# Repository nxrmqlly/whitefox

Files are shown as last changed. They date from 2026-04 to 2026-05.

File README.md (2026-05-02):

# whitefox :: an RP2350B devboard
> 💥 very chonky!

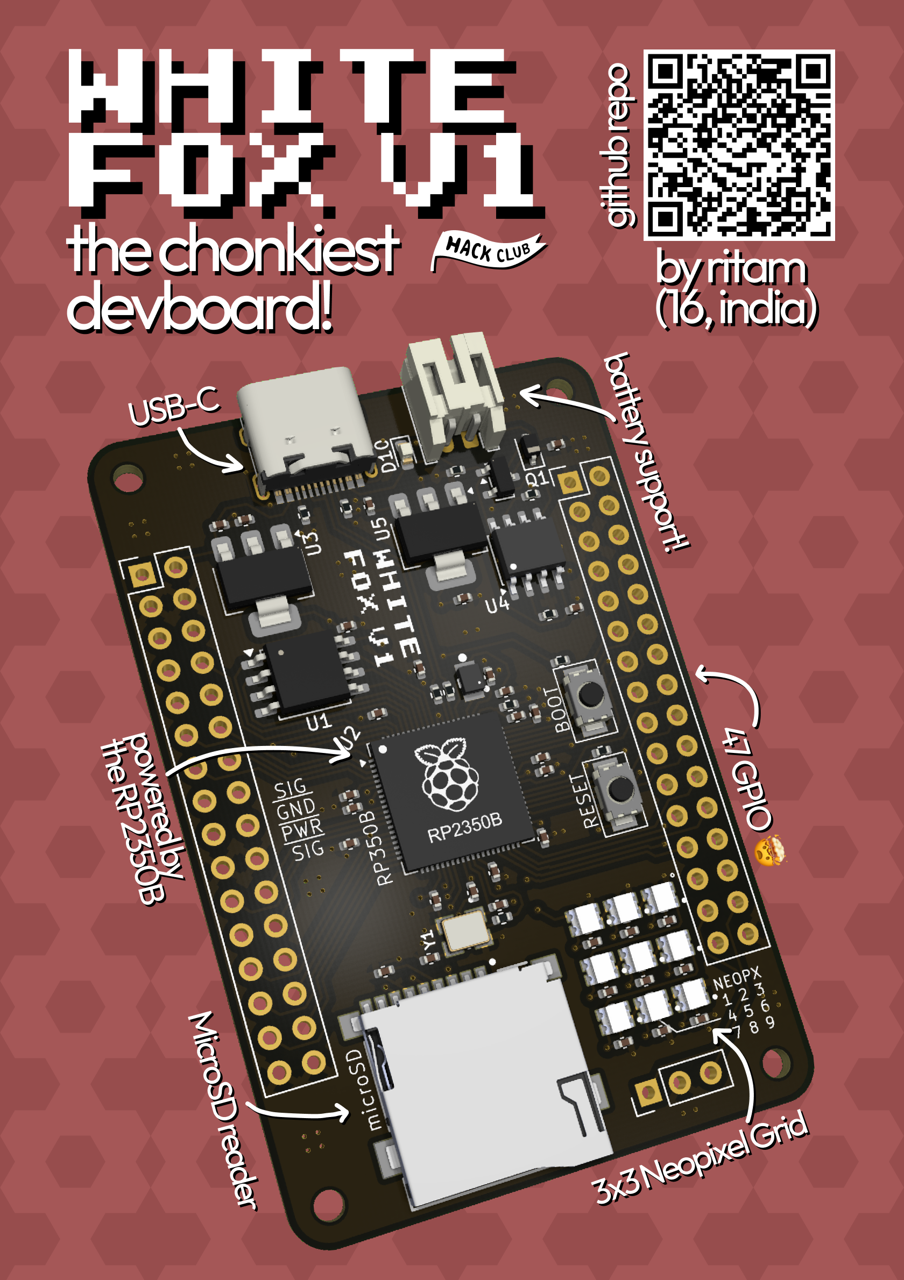
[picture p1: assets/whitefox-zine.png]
whitefox v1 magazine page


## What's this? ooh shiny.

whitefox is a Raspberry Pi RP2350B based **devboard** with *47 exposed GPIO, a 3x3 neopixel grid, a charging circuit and a MicroSD card reader* onboard!
Some may even say that it is *batteries included* but sorry we don't include batteries :(

## Why?

I wanted to have a go at making a devboard so I initially thought of using the RP2040 Chip but that thing is old now and very overused so here
we are with the RP2040's successor, the RP2350! Most RP2350 boards (like the Raspberry Pi Pico *2*) use the QFN-60 layout on the RP2350A chip 
and I haven't really seen devboards use the RP2350B, which is a QFN-80 chip, meaning it exposes the full power of the RP2350 in a bigger die.

## The PCB

The Schematic is a combination of very many different projects and the official and amazing
[Hardware design with RP2350](https://pip-assets.raspberrypi.com/categories/1214-rp2350/documents/RP-008280-DS-1-hardware-design-with-rp2350.pdf)
The PCB is configured in a 4 layer stackup as follows (from the top): `SIG / GND / PWR / SIG` and includes copper pours on all layers except
the PWR layer (duh.)
Most components are SMD on top of the board, only the JST connector is through hole.

The PCB exposes two 2x16 standard 2.54 mm pitch header holes on both sides and an additional 1x3 2.54mm pitch connector as a debug header.

| What | Image |
|---|---|
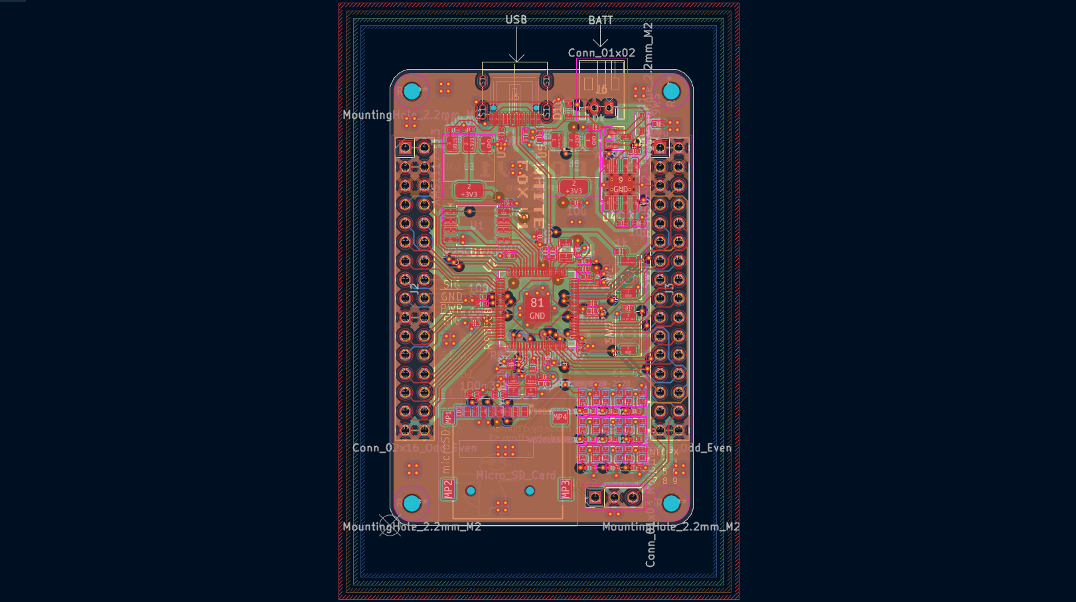
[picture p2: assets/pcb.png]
pcb
| [PCB](./Docs/whitefox-pcb.pdf) |  |
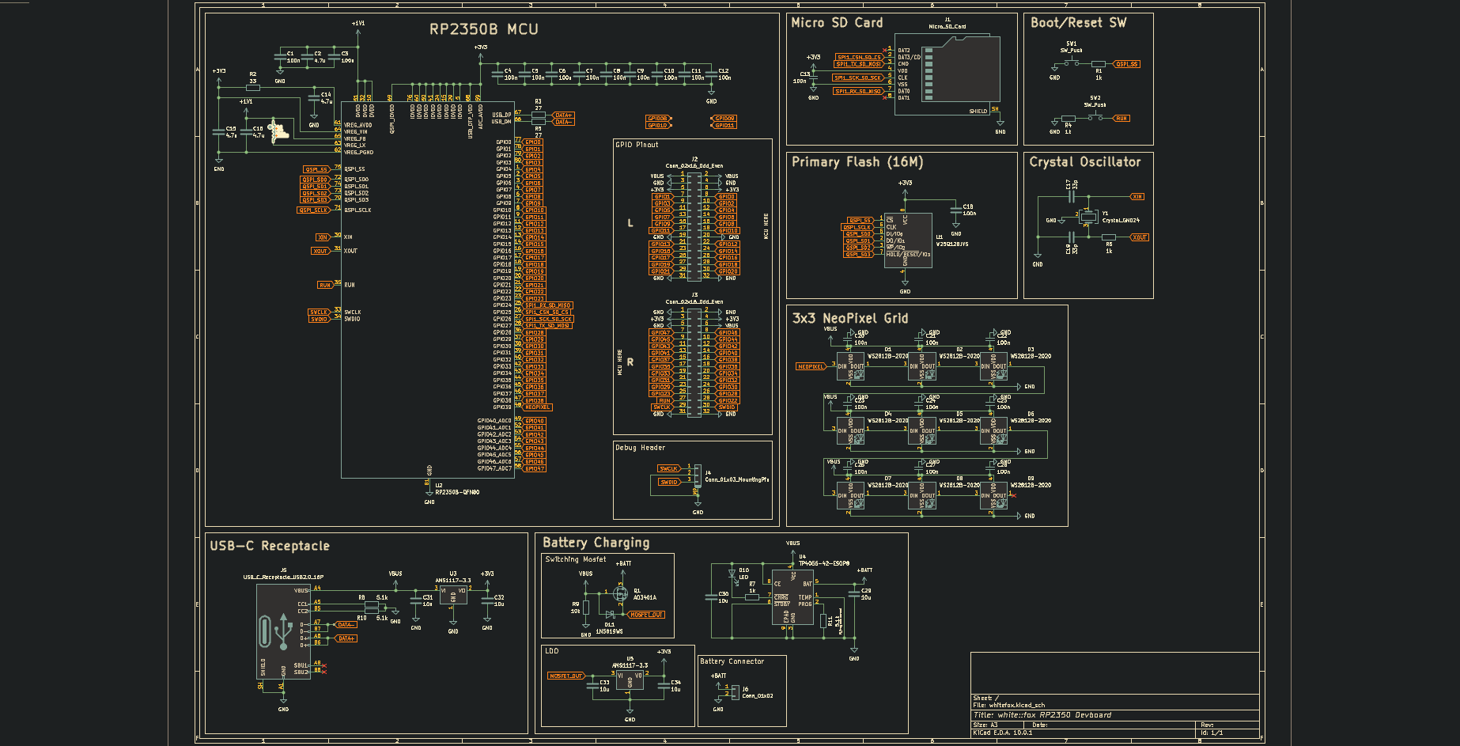
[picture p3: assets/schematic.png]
schematic
| [Schematic](./Docs/whitefox-schematic.pdf) |  |

The PCB and Schematic are available in a high quality PDFs in [Docs/](Docs/)

## 3D stuff
| <center>Front</center> | <center>Back</center> |
|---|---|
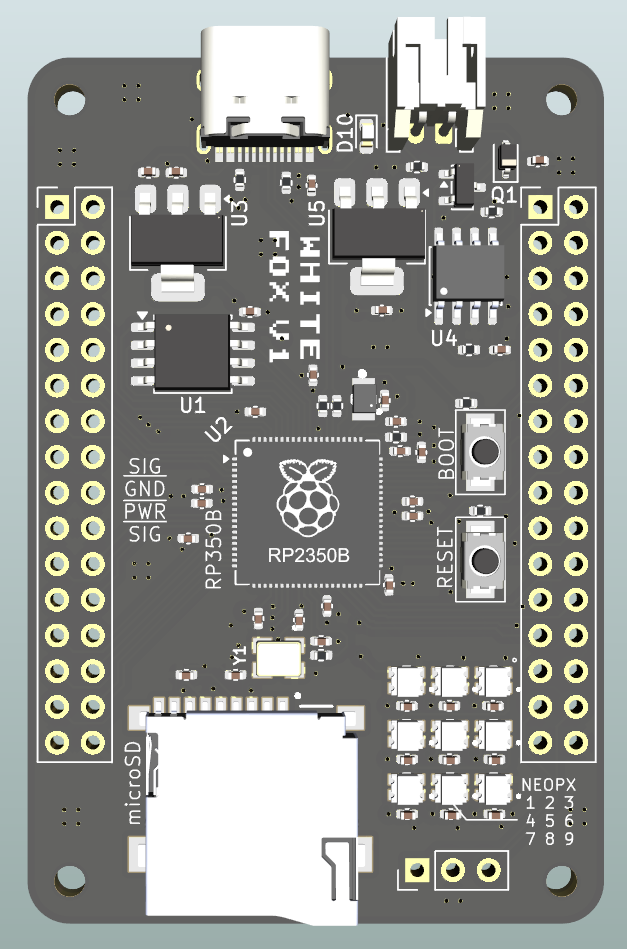
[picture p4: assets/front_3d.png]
3d front
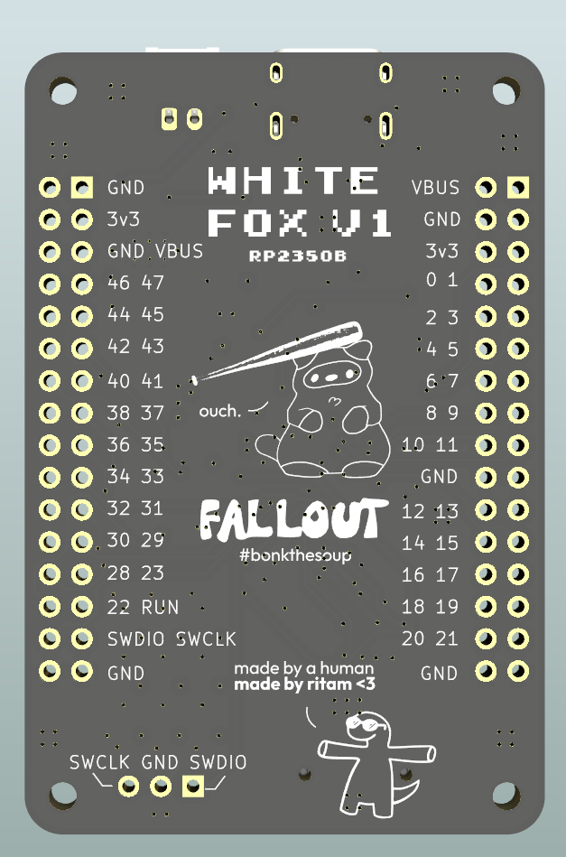
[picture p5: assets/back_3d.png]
3d back
|  |  |

## The BOM

Lazy to type it here so...

The full BOM can be found at [BOM/bom.csv](./BOM/BOM.csv)!

## Why the name?

> There are 2 hard problems in computer science: cache invalidation, **naming things**, and off-by-1 errors.
>
> *-- Leon Bambrick*

yeah that should be enough for an explanation.

## How to build / use it IRL

1. Spend some \$\$\$ get parts from the [BOM](./BOM/BOM.csv)
2. Use the gerbers from [production/gerbers.zip](production/gerbers.zip) to fabricate a PCB.
3. With some elbow grease and reference from the schematic, get to soldering the tiny SMD components
4. You're done! Go crazy

Alternatively, you can preserve your sanity and [get a PCBA service instead.](https://jlcpcb.com)
1. Gerbers are at [production/gerbers.zip](production/gerbers.zip)
2. JLCPCB BOM (not project bom!!) is at [production/jlc_bom.csv](production/jlc_bom.csv)
3. Pick and Place (CPL) file is at [production/positions.csv](production/positions.csv)

## Credits where credits are due.

Grateful for:
- [euvalennn's RPBoard^2](https://github.com/euvalennn/rpboard-squared) for a lot of design inspiration and schematic help.
- [Fallout by hackclub](https://fallout.hackclub.com/) for giving me the oppourtunity and public brand assets!
- hackclub slack for the coolest people that helped out!

## License

The hardware (PCB) is licensed under `CERN Open Hardware Licence Version 2 - Strongly Reciprocal` which means, you're all-right to copy my work and use it in yours but you must disclose your source code and project files to opensource repositories if you include part of my work in yours. See [LICENSE](LICENSE).

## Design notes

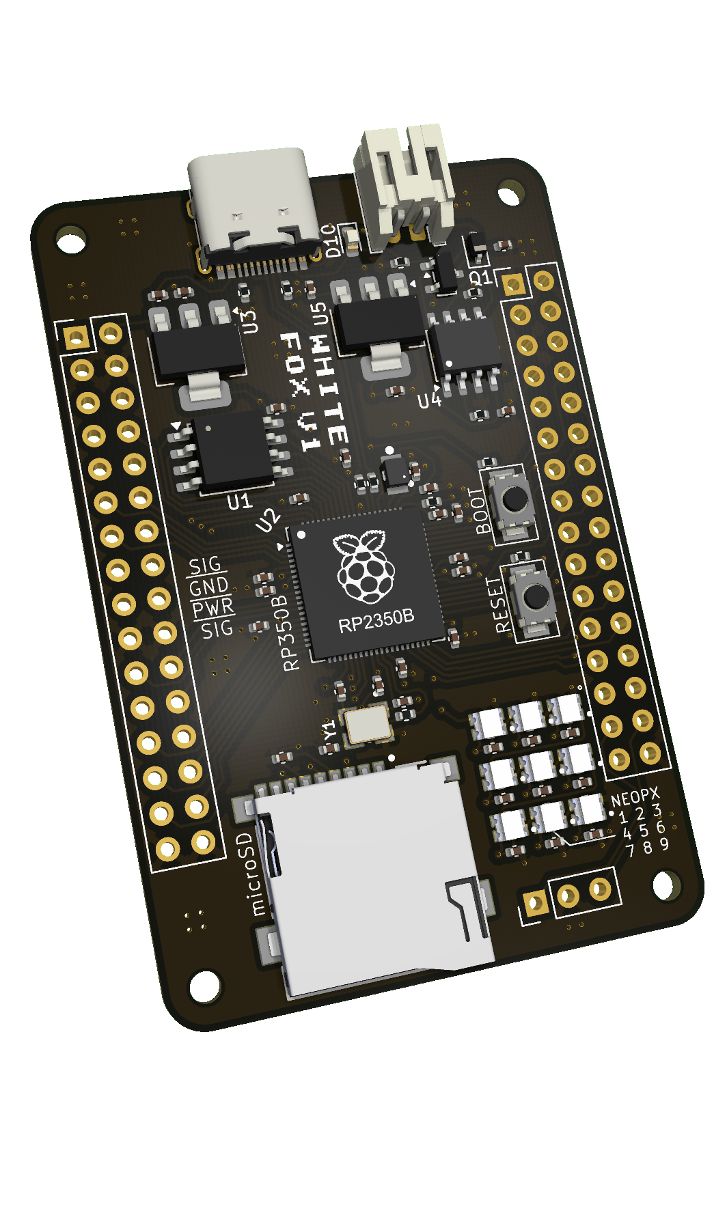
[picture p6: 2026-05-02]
assets/angled_3d_raytrace.png

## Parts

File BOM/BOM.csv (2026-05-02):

Name | Description | Quantity | JLCPCB Part # | Cost (USD) | Link | Notes
RP2350B | QFN-80-EP Microcontrollers (MCU/MPU/SOC) ROHS | 1 | C42415655 | 1.26 | https://jlcpcb.com/partdetail/RaspberryPi-RP2350B/C42415655 | Microcontroller
W25Q128JVSIQ | 128Mbit 133MHz SPI SOIC-8-208mil NOR FLASH ROHS | 1 | C97521 | 1.89 | https://jlcpcb.com/partdetail/WinbondElec-W25Q128JVSIQ/C97521 | 16M Flash QSPI
AMS1117-3.3 | 15V 1A 3.3V 5mA 72dB@(120Hz) Fixed Positive SOT-223 Voltage Regulators - Linear, Low Drop Out (LDO) Regulators ROHS | 2 | C6186 | 0.42 | https://jlcpcb.com/partdetail/Advanced_MonolithicSystems-AMS1117_33/C6186 | Voltage Regulator
TP4056-42-ESOP8 | Charging IC Lithium Battery Support ESOP-8 Battery Management ROHS | 1 | C16581 | 0.18 | https://jlcpcb.com/partdetail/17264-TP4056_42ESOP8/C16581 | Battery Manager
TF-01A | 1.85mm Connector and Ejector MicroSD Card (TF Card) Push-Push With Locating Pins SMD SD Card / Memory Card Connector ROHS | 1 | C91145 | 0.19 | https://jlcpcb.com/partdetail/Korean_HropartsElec-TF01A/C91145 | MicroSD Push-Push
X322512MSB4SI | -40℃~+85℃ 12MHz 20pF Crystal Oscillator ±10ppm ±20ppm SMD3225-4P Crystals ROHS | 1 | C9002 | 0.07 | https://jlcpcb.com/partdetail/YXC_CrystalOscillators-X322512MSB4SI/C9002 | Crystal
TS-1088-AR02016 | 12V 2mm 3mm 4mm 50mA Black Round Button SMD(SMT) Tactile Switches ROHS | 2 | C720477 | 0.12 | https://jlcpcb.com/partdetail/XUNPU-TS_1088AR02016/C720477 | Boot/Reset SW
WS2812C-2020-V1 | SMD, 2x2mm RGB LEDs(Built-in IC) ROHS | 9 | C2976072 | 0.87 | https://jlcpcb.com/partdetail/Worldsemi-WS2812C_2020V1/C2976072 | NeoPixel 2020
TYPE-C-31-M-12 | Right Angle Type-C SMD USB Connectors ROHS | 1 | C165948 | 0.18 | https://jlcpcb.com/partdetail/Korean_HropartsElec-TYPE_C_31_M12/C165948 | USB-C Receptacle
AO3401A | 1 P-Channel 14nC@10V 30V 47mΩ@10V、60mΩ@4.5V、85mΩ@2.5V 4A 55pF 645pF 80pF 900mV SOT-23 MOSFETs ROHS | 1 | C15127 | 0.06 | https://jlcpcb.com/partdetail/Alpha_OmegaSemicon-AO3401A/C15127 | Mosfet
AOTA-B201610S3R3-101-T | 0806 Power Inductors ROHS | 1 | C42411119 | 0.29 | https://jlcpcb.com/partdetail/AbraconLLC-AOTA_B201610S3R3_101T/C42411119 | 3.3uH
KT-0603R | 1.8V~2.4V 120° 20mA 300mcd 40mW 615nm~630nm 645nm Discrete Diode Red Water Clear 0603 LED Indication - Discrete ROHS | 1 | C2286 | 0.01 | https://jlcpcb.com/partdetail/Hubei_KENTOElec-KT0603R/C2286 | Red LED
1N5819WS | SOD-323 Schottky Diodes ROHS | 1 | C191023 | 0.01 | https://jlcpcb.com/partdetail/GuangdongHottech-1N5819WS/C191023 | Diode
CL05B104KO5NNNC | 100nF 16V X7R ±10% 0402 Multilayer Ceramic Capacitors MLCC - SMD/SMT ROHS | 22 | C1525 | 0.03 | https://jlcpcb.com/partdetail/1877-CL05B104KO5NNNC/C1525 | 100nF
CL05A475MP5NRNC | 10V 4.7uF X5R ±20% 0402 Multilayer Ceramic Capacitors MLCC - SMD/SMT ROHS | 4 | C23733 | 0.02 | https://jlcpcb.com/partdetail/24469-CL05A475MP5NRNC/C23733 | 4.7uF
0402CG330J500NT | 33pF 50V C0G ±5% 0402 Multilayer Ceramic Capacitors MLCC - SMD/SMT ROHS | 2 | C1562 | 0.01 | https://jlcpcb.com/partdetail/1914-0402CG330J500NT/C1562 | 33pF
CL05A475MP5NRNC | 10uF 6.3V X5R ±20% 0402 Multilayer Ceramic Capacitors MLCC - SMD/SMT ROHS | 6 | C15525 | 0.04 | https://jlcpcb.com/partdetail/16204-CL05A106MQ5NUNC/C15525 | 10uF
0402WGF1001TCE | 1kΩ 50V 62.5mW Thick Film Resistor ±1% ±100ppm/℃ 0402 Chip Resistor - Surface Mount ROHS | 4 | C11702 | 0.01 | https://jlcpcb.com/partdetail/12256-0402WGF1001TCE/C11702 | 1k ohm
0402WGF330JTCE | 33Ω 50V 62.5mW Thick Film Resistor ±1% ±100ppm/℃ 0402 Chip Resistor - Surface Mount ROHS | 1 | C25105 | 0.01 | https://jlcpcb.com/partdetail/25848-0402WGF330JTCE/C25105 | 33 ohm
0402WGF270JTCE | 27Ω 50V 62.5mW Thick Film Resistor ±1% ±100ppm/℃ 0402 Chip Resistor - Surface Mount ROHS | 2 | C25100 | 0.01 | https://jlcpcb.com/partdetail/25843-0402WGF270JTCE/C25100 | 27 ohm
0402WGF1002TCE | 10kΩ 50V 62.5mW Thick Film Resistor ±1% ±100ppm/℃ 0402 Chip Resistor - Surface Mount ROHS | 1 | C25744 | 0.01 | https://jlcpcb.com/partdetail/26487-0402WGF1002TCE/C25744 | 10k ohm
0402WGF5101TCE | 5.1kΩ 50V 62.5mW Thick Film Resistor ±1% ±100ppm/℃ 0402 Chip Resistor - Surface Mount ROHS | 3 | C25905 | 0.01 | https://jlcpcb.com/partdetail/26648-0402WGF5101TCE/C25905 | 5.1k ohm
S2B-PH-K-S(LF)(SN) | 2mm 4.8mm 5.9mm 7.6mm Brass K Pin PA66 PH Right Angle Tin UL94V-0 White P=2mm Wire To Board Connector ROHS | 1 | C173752 | 0.04 | https://jlcpcb.com/partdetail/JST-S2B_PH_K_S_LF_SN/C173752 | JST Connector PH
PARTS TOTAL |  |  |  | 5.74
JLCPCB PCB | 4-layer, 1.6mm, Black | 5 |  | 14.9
JLCPCB PCBA | PCB Assembly (Including Parts) | 2 |  | 86.16
Baking Cost |  |  |  | 7.29 |  | For LEDs
HARDWARE TOTAL |  |  |  | 108.35
SHIPPING |  |  |  | 9.02
DISCOUNT |  |  |  | 0 |  | To be added
GRAND TOTAL |  |  |  | 117.37

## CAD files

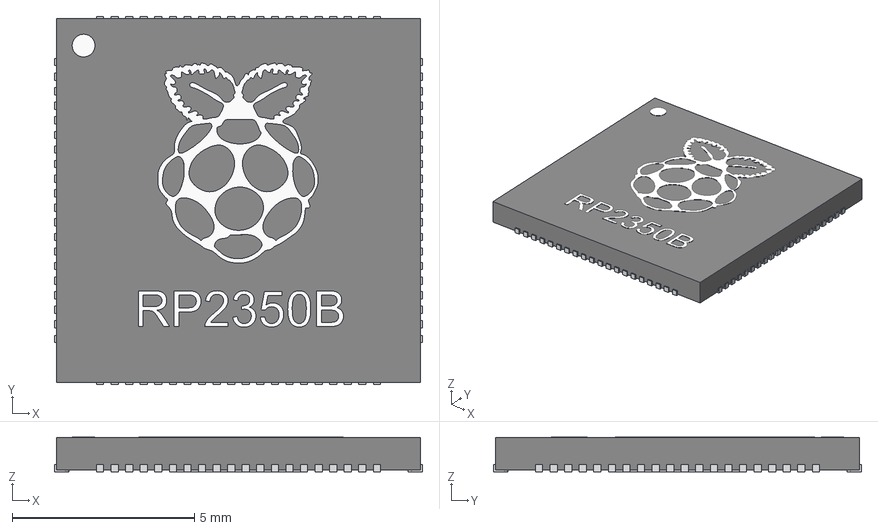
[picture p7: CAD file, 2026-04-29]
3d/RP2350/RP2350B.stp
10.1 x 10.1 x 0.96 mm

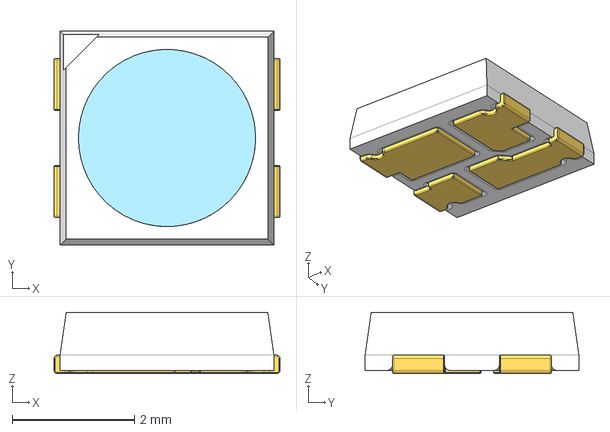
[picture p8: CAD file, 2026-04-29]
3d/SK6812-SMD3535/SK6812-SMD3535.stp
3.70 x 3.50 x 1.00 mm

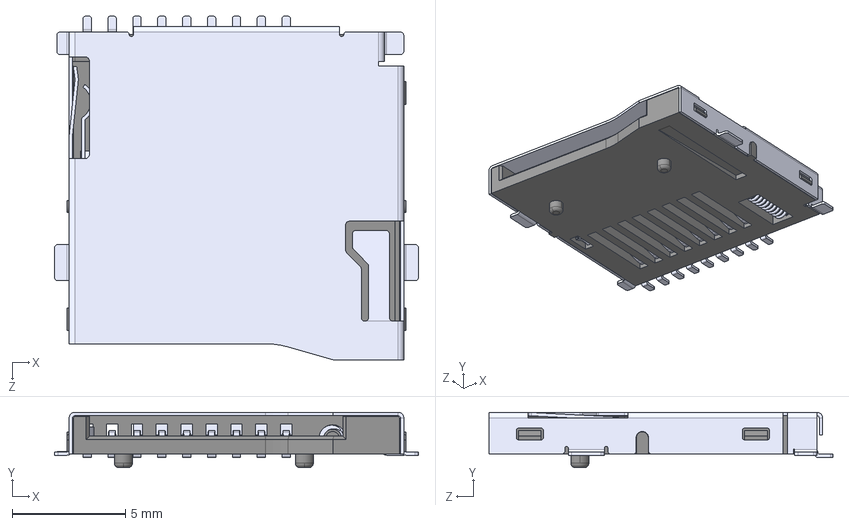
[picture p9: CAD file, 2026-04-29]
3d/TF-01A/TF-01A.STEP
16.1 x 2.45 x 15.2 mm

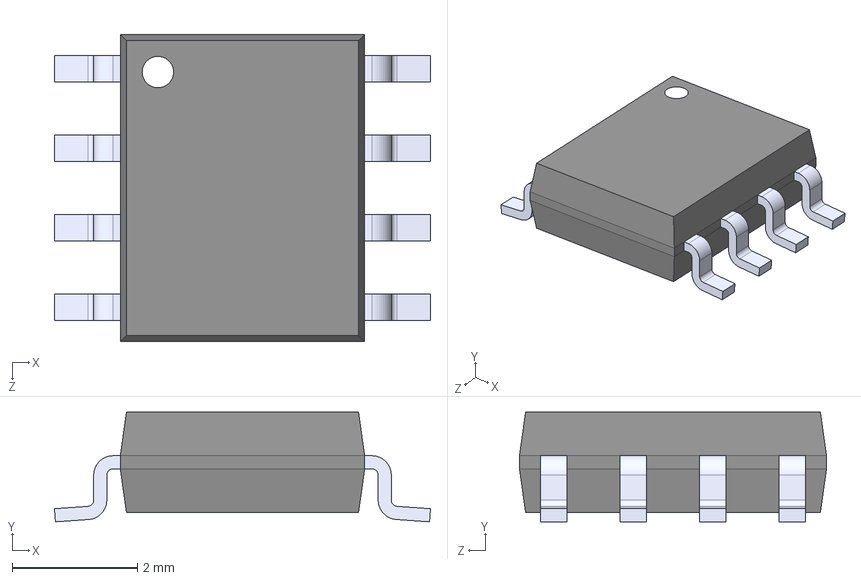
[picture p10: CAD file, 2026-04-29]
3d/TP4046-42-ESOP8/TP4056-42-ESOP8.STEP
6.00 x 1.75 x 4.90 mm

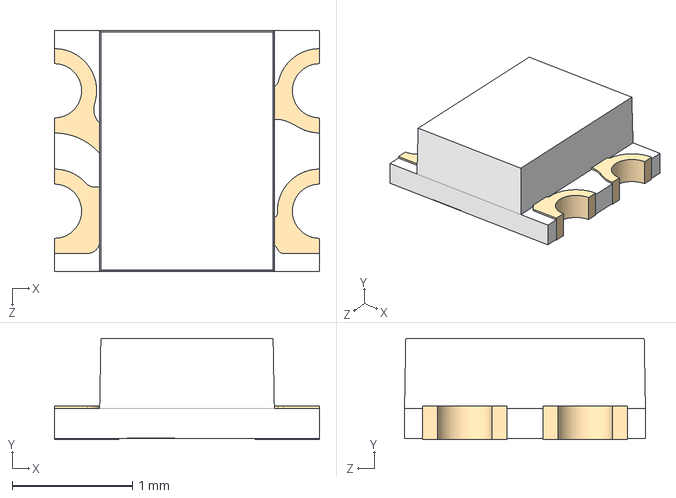
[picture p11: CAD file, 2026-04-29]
3d/WS2812B-2020/WS2812B-2020.STEP
2.20 x 0.84 x 2.00 mm

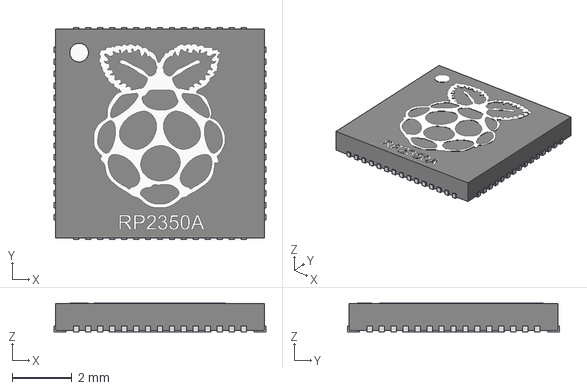
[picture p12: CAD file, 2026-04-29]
3d/RP2350/RP2350A.stp
7.10 x 7.10 x 0.96 mm

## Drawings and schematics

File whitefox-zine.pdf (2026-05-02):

## white

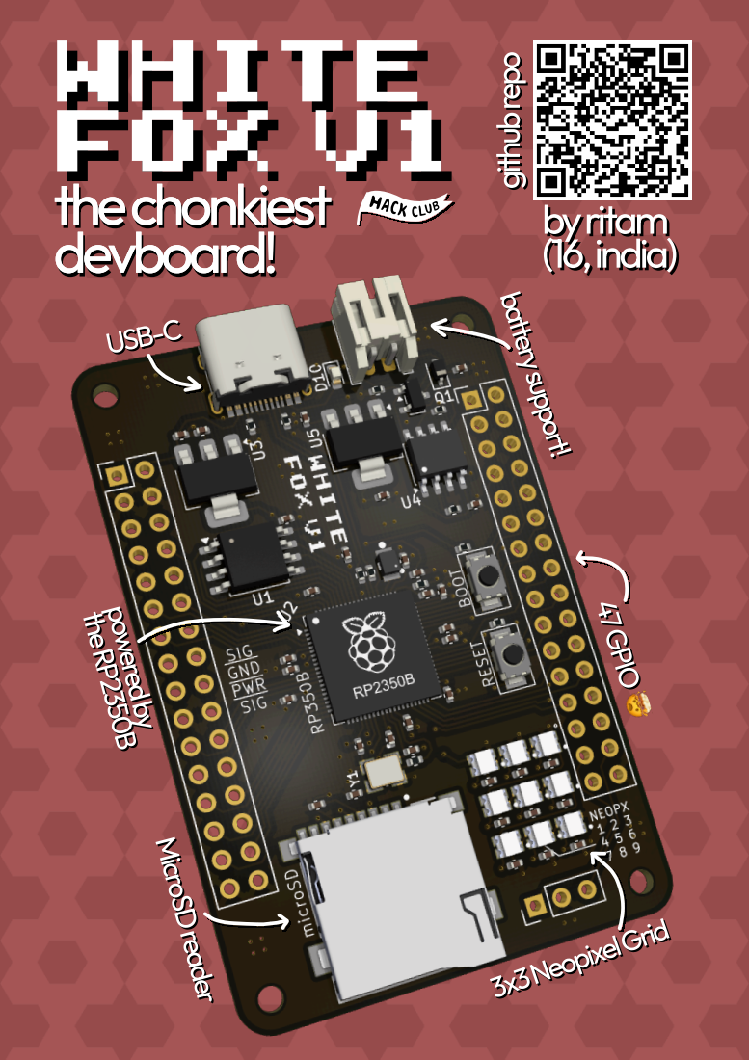
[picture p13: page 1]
fox; v1 the chonkiest; devboard!; USB-C; github repo; by ritam (16, india) battery support!; the RP2350B; powered by; MicroSD reader; 3x3 Neopixel Grid; 47 GPIO

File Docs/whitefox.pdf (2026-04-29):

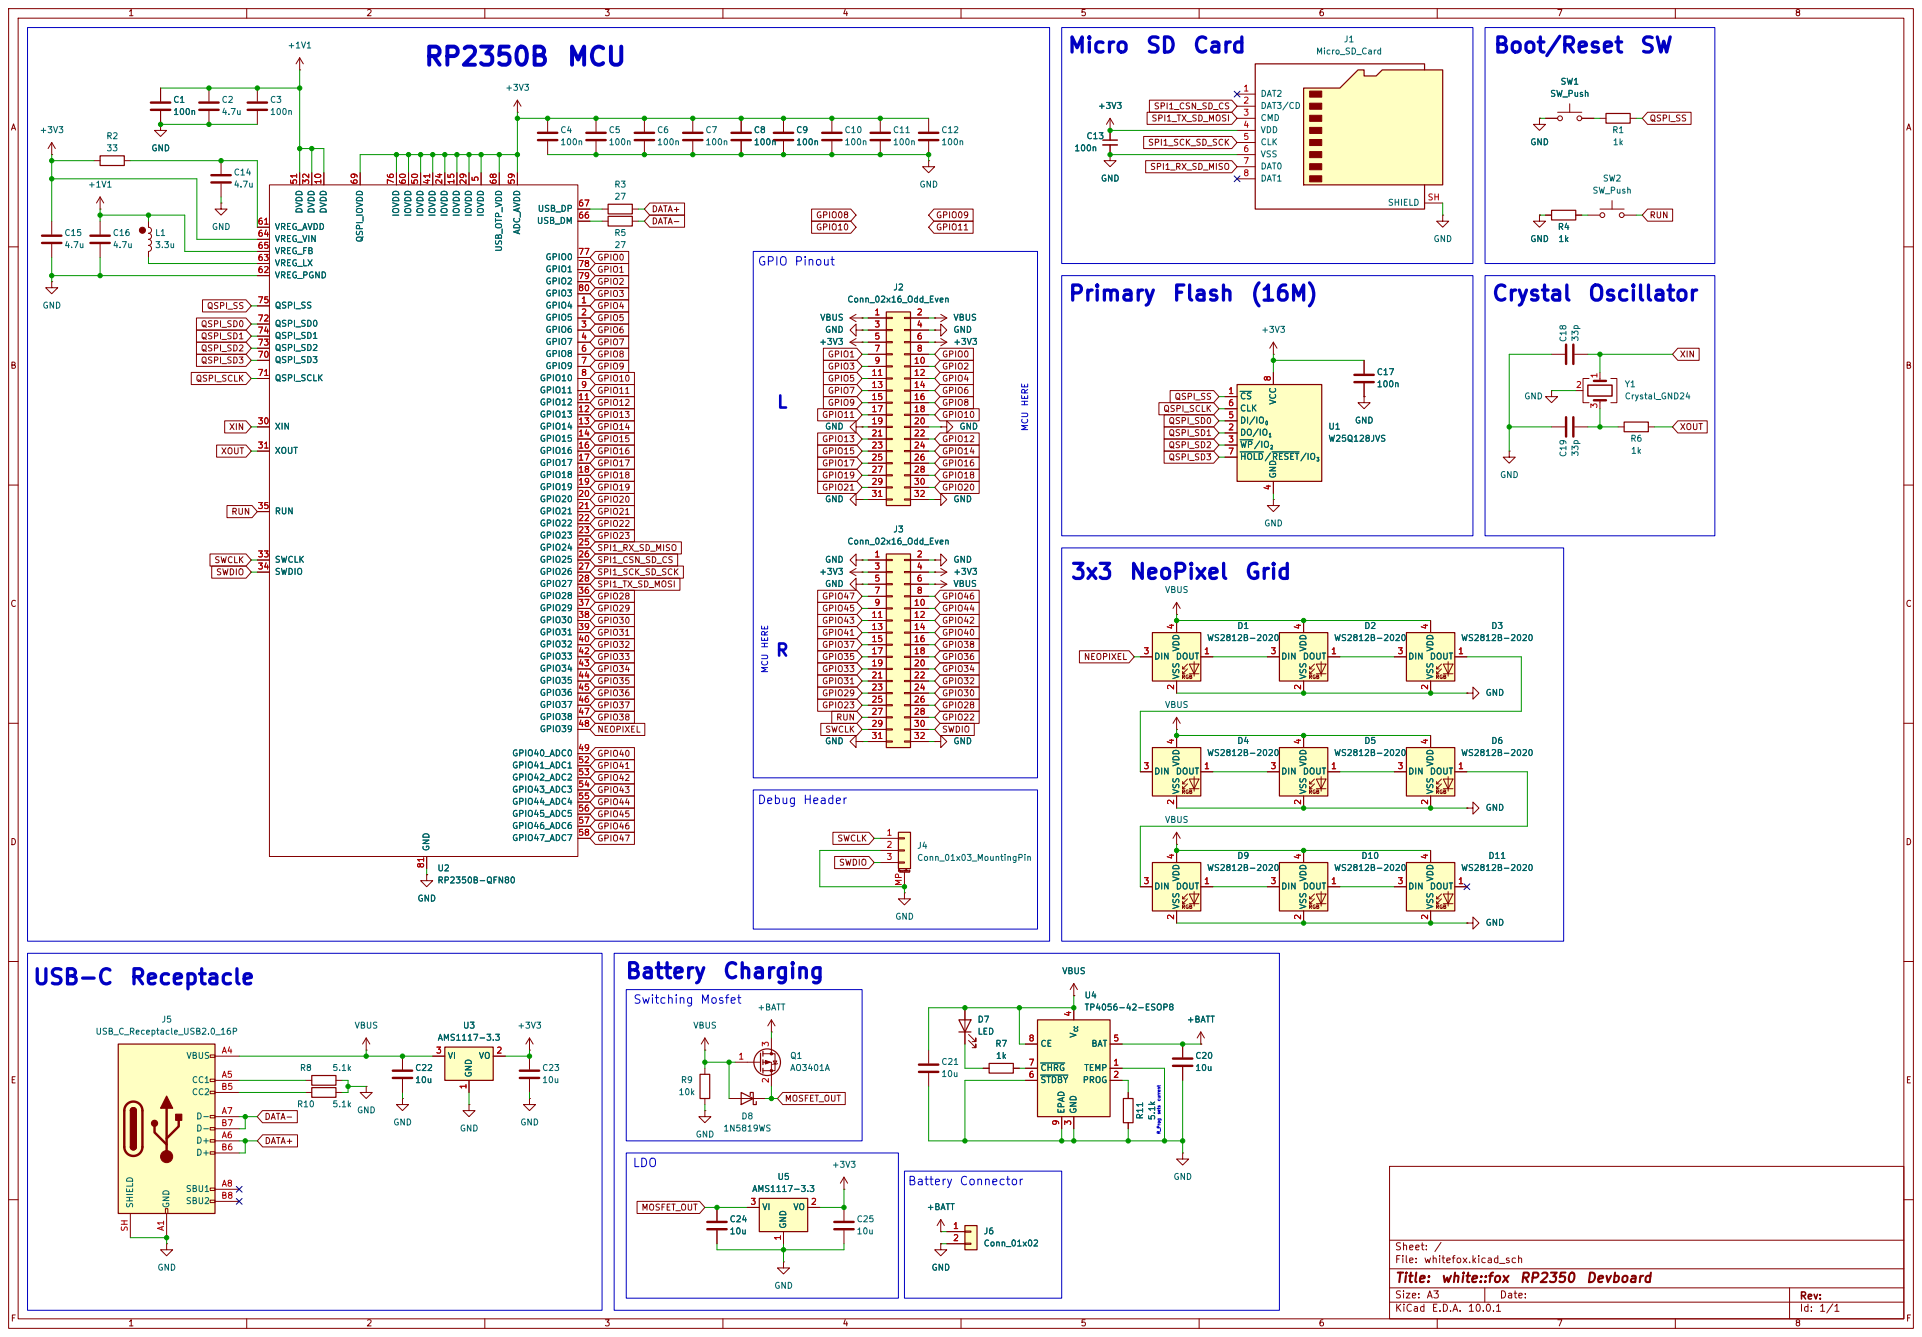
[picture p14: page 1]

Boot/Reset SW R_Prog sets current

5 GPIO8 6 GPIO9 7 GPIO10 8 GPIO11 9 DVDD 10 GPIO12 11 GPIO13 12 GPIO14 13 GPIO15 14 IOVDD 15 GPIO16 16 GPIO17 17 GPIO18 18 GPIO19 19 GPIO20 20 GPIO21 21 GPIO22 22 GPIO23 23 IOVDD 24 GPIO24 25 GPIO25 26 GPIO26 27 GPIO27 28 IOVDD 29

4 DI/IO0 5 CLK 6 HOLD/RESET/IO3 7 VCC

J3 Conn_02x16_Odd_Even +3V3 GND
3x3 NeoPixel Grid MCU HERE

LDO

Sheet: /
File: whitefox.kicad_sch
Title: white::fox RP2350 Devboard

Size: A3 | Rev: | F Date:
KiCad E.D.A. 10.0.1 | Id: 1/1

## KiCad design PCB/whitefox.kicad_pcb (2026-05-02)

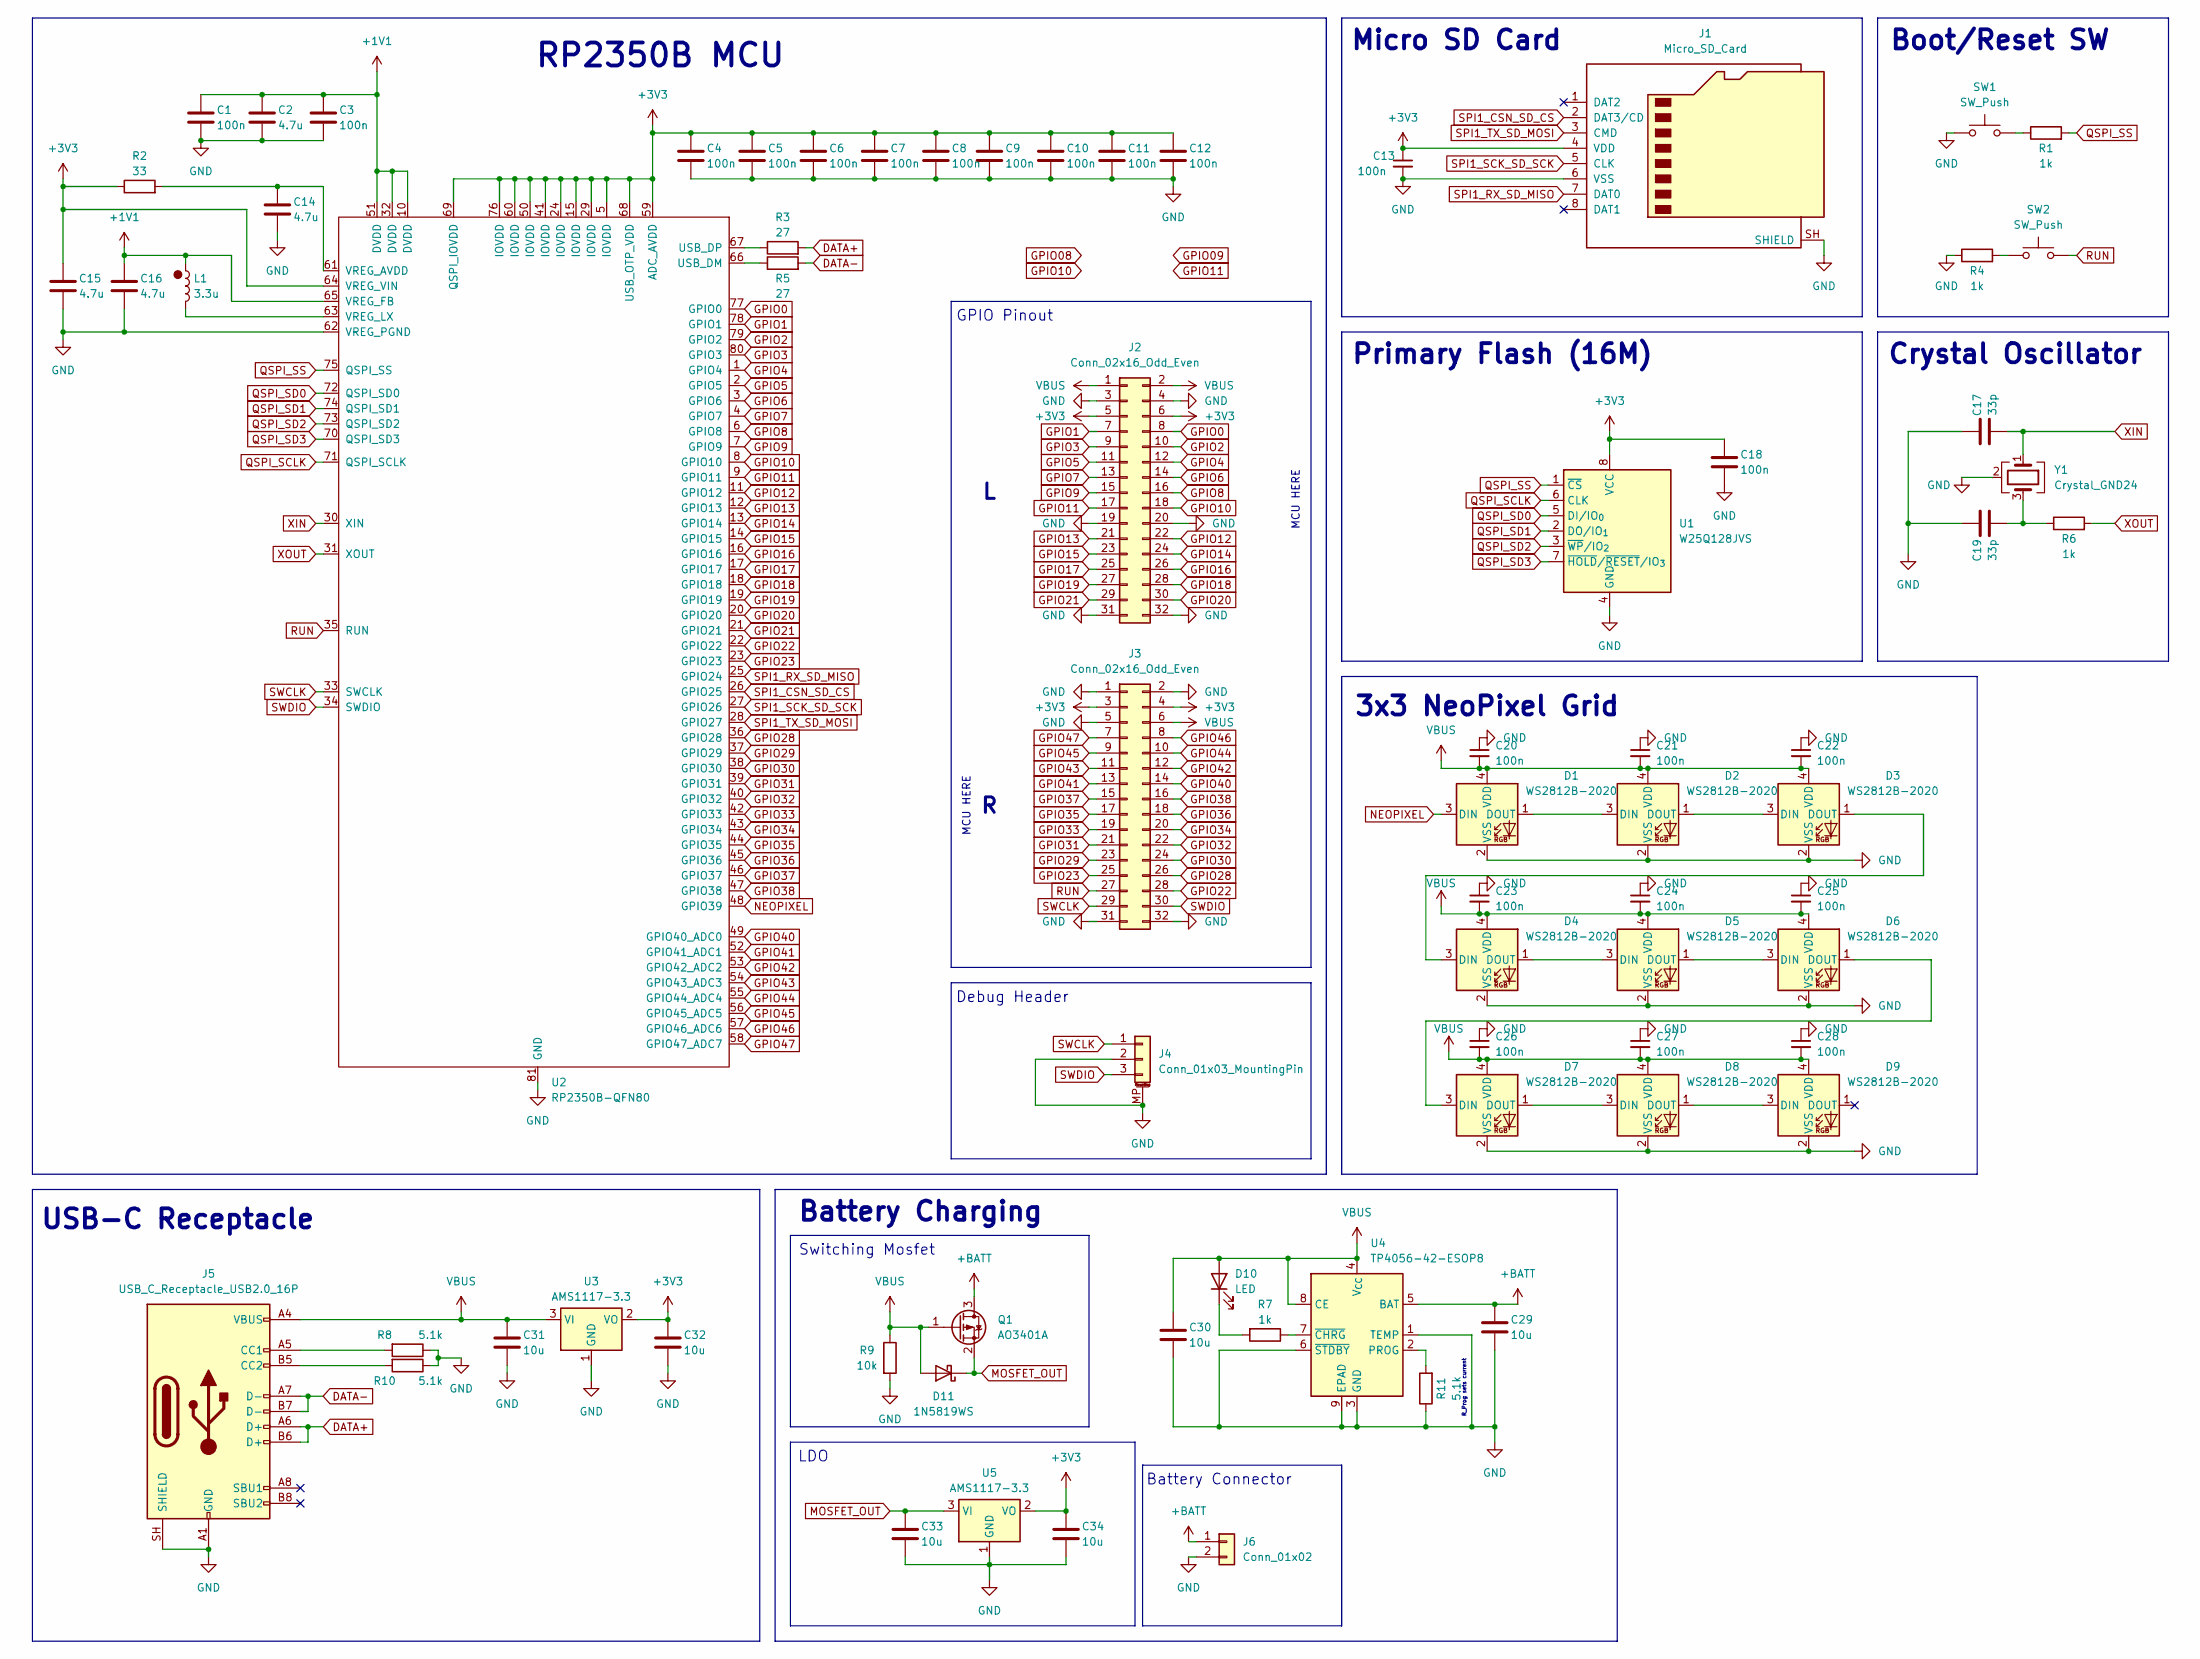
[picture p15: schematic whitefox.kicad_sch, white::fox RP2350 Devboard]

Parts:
C1, C3, C4, C5, C6, C7, C8, C9, C10, C11, C12, C13, C18, C20, C21, C22, C23, C24, C25, C26, C27, C28: 100n; C_0402_1005Metric
C2, C14, C15, C16: 4.7u; C_0402_1005Metric
C17, C19: 33p; C_0402_1005Metric
C29, C30, C31, C32, C33, C34: 10u; C_0402_1005Metric
D1, D2, D3, D4, D5, D6, D7, D8, D9: WS2812B-2020; LED_WS2812C-2020
D10: LED; LED_0603_1608Metric
D11: 1N5819WS; D_SOD-323
J1: Micro_SD_Card; TF-01A
J2, J3: Conn_02x16_Odd_Even; PinHeader_2x16_P2.54mm_Vertical
J4: Conn_01x03_MountingPin; PinHeader_1x03_P2.54mm_Vertical
J5: USB_C_Receptacle_USB2.0_16P; TYPE-C-31-M-12
J6: Conn_01x02; JST_PH_S2B-PH-K_1x02_P2.00mm_Horizontal
L1: 3.3u; IND-SMD_L2.0-W1.6_AOTA-B201610S3R3-101-T
Q1: AO3401A; SOT-23
R1, R4, R6, R7: 1k; R_0402_1005Metric
R2: 33; R_0402_1005Metric
R3, R5: 27; R_0402_1005Metric
R8, R10, R11: 5.1k; R_0402_1005Metric
R9: 10k; R_0402_1005Metric
SW1, SW2: SW_Push; TS-1088-ARXXX
U1: W25Q128JVS; SOIC-8_5.3x5.3mm_P1.27mm
U2: RP2350B-QFN80; QFN-80-1EP_10x10mm_P0.4mm_EP3.4x3.4mm
U3, U5: AMS1117-3.3; SOT-223-3_TabPin2
U4: TP4056-42-ESOP8; SOIC-8-1EP_3.9x4.9mm_P1.27mm_EP2.41x3.3mm_ThermalVias
Y1: Crystal_GND24; XTAL_ABM8-272-T3

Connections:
+1V1: C1.1, C2.1, C3.1, C16.2, L1.1, U2.10 (DVDD), U2.32 (DVDD), U2.51 (DVDD), U2.65 (VREG_FB)
+3V3: C4.1, C5.1, C6.1, C7.1, C8.1, C9.1, C10.1, C11.1, C12.1, C13.1, C15.1, C18.1, C32.1, C34.1, J1.4 (VDD), J2.5, J2.6, J3.3, J3.4, R2.1, U1.8 (VCC), U2.5 (IOVDD), U2.15 (IOVDD), U2.24 (IOVDD), U2.29 (IOVDD), U2.41 (IOVDD), U2.50 (IOVDD), U2.59 (ADC_AVDD), U2.60 (IOVDD), U2.64 (VREG_VIN), U2.68 (USB_OTP_VDD), U2.69 (QSPI_IOVDD), U2.76 (IOVDD), U3.2 (VO), U5.2 (VO)
+BATT: C29.1, J6.1, Q1.3 (D), U4.5 (BAT)
DATA+: J5.A6 (D+), J5.B6 (D+), R3.2
DATA-: J5.A7 (D-), J5.B7 (D-), R5.2
GND: C1.2, C2.2, C3.2, C4.2, C5.2, C6.2, C7.2, C8.2, C9.2, C10.2, C11.2, C12.2, C13.2, C14.2, C15.2, C16.1, C17.2, C18.2, C19.2, C20.1, C21.1, C22.1, C23.1, C24.1, C25.1, C26.1, C27.1, C28.1, C29.2, C30.2, C31.2, C32.2, C33.2, C34.2, D1.2 (VSS), D2.2 (VSS), D3.2 (VSS), D4.2 (VSS), D5.2 (VSS), D6.2 (VSS), D7.2 (VSS), D8.2 (VSS), D9.2 (VSS), J1.6 (VSS), J1.SH (SHIELD), J2.3, J2.4, J2.19, J2.20, J2.31, J2.32, J3.1, J3.2, J3.5, J3.31, J3.32, J4.2, J4.MP (MountPin), J5.A1 (GND), J5.A12 (GND), J5.B1 (GND), J5.B12 (GND), J5.SH (SHIELD), J6.2, R4.1, R8.1, R9.2, R10.1, R11.1, SW1.1, U1.4 (GND), U2.62 (VREG_PGND), U2.81 (GND), U3.1 (GND), U4.1 (TEMP), U4.3 (GND), U4.6 (~STDBY), U4.9 (EPAD), U5.1 (GND), Y1.2 (G), Y1.4 (G)
GPIO0: J2.8, U2.77 (GPIO0)
GPIO1: J2.7, U2.78 (GPIO1)
GPIO2: J2.10, U2.79 (GPIO2)
GPIO3: J2.9, U2.80 (GPIO3)
GPIO4: J2.12, U2.1 (GPIO4)
GPIO5: J2.11, U2.2 (GPIO5)
GPIO6: J2.14, U2.3 (GPIO6)
GPIO7: J2.13, U2.4 (GPIO7)
GPIO8: J2.16, U2.6 (GPIO8)
GPIO9: J2.15, U2.7 (GPIO9)
GPIO10: J2.18, U2.8 (GPIO10)
GPIO11: J2.17, U2.9 (GPIO11)
GPIO12: J2.22, U2.11 (GPIO12)
GPIO13: J2.21, U2.12 (GPIO13)
GPIO14: J2.24, U2.13 (GPIO14)
GPIO15: J2.23, U2.14 (GPIO15)
GPIO16: J2.26, U2.16 (GPIO16)
GPIO17: J2.25, U2.17 (GPIO17)
GPIO18: J2.28, U2.18 (GPIO18)
GPIO19: J2.27, U2.19 (GPIO19)
GPIO20: J2.30, U2.20 (GPIO20)
GPIO21: J2.29, U2.21 (GPIO21)
GPIO22: J3.28, U2.22 (GPIO22)
GPIO23: J3.25, U2.23 (GPIO23)
GPIO28: J3.26, U2.36 (GPIO28)
GPIO29: J3.23, U2.37 (GPIO29)
GPIO30: J3.24, U2.38 (GPIO30)
GPIO31: J3.21, U2.39 (GPIO31)
GPIO32: J3.22, U2.40 (GPIO32)
GPIO33: J3.19, U2.42 (GPIO33)
GPIO34: J3.20, U2.43 (GPIO34)
GPIO35: J3.17, U2.44 (GPIO35)
GPIO36: J3.18, U2.45 (GPIO36)
GPIO37: J3.15, U2.46 (GPIO37)
GPIO38: J3.16, U2.47 (GPIO38)
GPIO40: J3.14, U2.49 (GPIO40_ADC0)
GPIO41: J3.13, U2.52 (GPIO41_ADC1)
GPIO42: J3.12, U2.53 (GPIO42_ADC2)
GPIO43: J3.11, U2.54 (GPIO43_ADC3)
GPIO44: J3.10, U2.55 (GPIO44_ADC4)
GPIO45: J3.9, U2.56 (GPIO45_ADC5)
GPIO46: J3.8, U2.57 (GPIO46_ADC6)
GPIO47: J3.7, U2.58 (GPIO47_ADC7)
MOSFET_OUT: C33.1, D11.1 (K), Q1.2 (S), U5.3 (VI)
NEOPIXEL: D1.3 (DIN), U2.48 (GPIO39)
unnamed: C19.1, R6.1, Y1.3
unnamed: D1.1 (DOUT), D2.3 (DIN)
unnamed: D2.1 (DOUT), D3.3 (DIN)
unnamed: D3.1 (DOUT), D4.3 (DIN)
unnamed: D4.1 (DOUT), D5.3 (DIN)
unnamed: D5.1 (DOUT), D6.3 (DIN)
unnamed: D6.1 (DOUT), D7.3 (DIN)
unnamed: D7.1 (DOUT), D8.3 (DIN)
unnamed: D8.1 (DOUT), D9.3 (DIN)
unnamed: D10.1 (K), R7.2
unnamed: J5.A5 (CC1), R8.2
unnamed: J5.B5 (CC2), R10.2
unnamed: R1.1, SW1.2
unnamed: R4.2, SW2.1
unnamed: R5.1, U2.66 (USB_DM)
unnamed: R3.1, U2.67 (USB_DP)
unnamed: C14.1, R2.2, U2.61 (VREG_AVDD)
unnamed: L1.2, U2.63 (VREG_LX)
unnamed: R11.2, U4.2 (PROG)
unnamed: R7.1, U4.7 (~CHRG)
QSPI_SCLK: U1.6 (CLK), U2.71 (QSPI_SCLK)
QSPI_SD0: U1.5 (DI/IO_{0}), U2.72 (QSPI_SD0)
QSPI_SD1: U1.2 (DO/IO_{1}), U2.74 (QSPI_SD1)
QSPI_SD2: U1.3 (~WP/IO_{2}), U2.73 (QSPI_SD2)
QSPI_SD3: U1.7 (~HOLD/~RESET/IO_{3}), U2.70 (QSPI_SD3)
QSPI_SS: R1.2, U1.1 (~CS), U2.75 (QSPI_SS)
RUN: J3.27, SW2.2, U2.35 (RUN)
SPI1_CSN_SD_CS: J1.2 (DAT3/CD), U2.26 (GPIO25)
SPI1_RX_SD_MISO: J1.7 (DAT0), U2.25 (GPIO24)
SPI1_SCK_SD_SCK: J1.5 (CLK), U2.27 (GPIO26)
SPI1_TX_SD_MOSI: J1.3 (CMD), U2.28 (GPIO27)
SWCLK: J3.29, J4.1, U2.33 (SWCLK)
SWDIO: J3.30, J4.3, U2.34 (SWDIO)
VBUS: C20.2, C21.2, C22.2, C23.2, C24.2, C25.2, C26.2, C27.2, C28.2, C30.1, C31.1, D1.4 (VDD), D2.4 (VDD), D3.4 (VDD), D4.4 (VDD), D5.4 (VDD), D6.4 (VDD), D7.4 (VDD), D8.4 (VDD), D9.4 (VDD), D10.2 (A), D11.2 (A), J2.1, J2.2, J3.6, J5.A4 (VBUS), J5.A9 (VBUS), J5.B4 (VBUS), J5.B9 (VBUS), Q1.1 (G), R9.1, U3.3 (VI), U4.4 (V_{CC}), U4.8 (CE)
XIN: C17.1, U2.30 (XIN), Y1.1
XOUT: R6.2, U2.31 (XOUT)

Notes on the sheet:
RP2350B MCU
MCU HERE
Battery Charging
LDO
Debug Header
USB-C Receptacle
Switching Mosfet
Boot/Reset SW
R_Prog sets current
Crystal Oscillator
3x3 NeoPixel Grid
Battery Connector
GPIO Pinout
Primary Flash (16M)
Micro SD Card

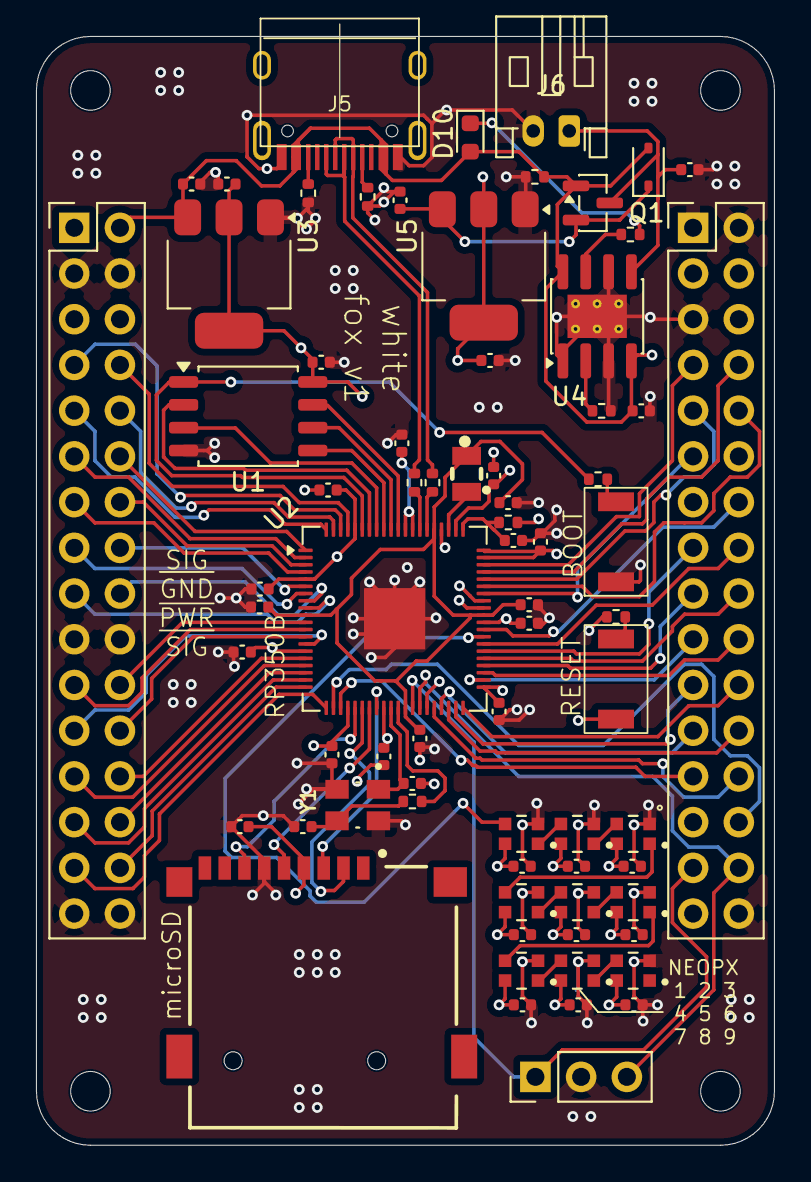
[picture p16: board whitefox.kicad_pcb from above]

Board: 4 copper layers, 41.0 x 61.6 mm, 72 parts (0 on the bottom side), 87 nets.

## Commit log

2026-04-29 upload to github
    [BOM.csv, BOM.xlsx, RP2350A.stp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]
2026-05-02 add decoupling caps
    [BOM.csv, BOM.xlsx, designators.csv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]
